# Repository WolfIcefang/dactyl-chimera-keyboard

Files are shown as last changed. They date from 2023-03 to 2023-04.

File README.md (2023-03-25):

# dactyl-chimera-keyboard

## A mechanical keyboard designed for 3D printing, tinkering, and experimentation.





This project aims to provide a "test bench" for various column curvatures in mechanical keyboards. Potential side effects include: shorter 3d printing times, instant fine-tuning of column height and stagger, [adjustable tenting](https://youtu.be/rMioYSjqEoU), and comfortable computer usage. Interchangable thumb clusters are also a goal of the project, but currently there's only one thumb cluster to choose from.

Dactyl Chimera (DC)'s primary purpose is as a testing and research tool. It is not designed to look stylish, sound spectacular, or increase compactness. If you do not mind a couple (dozen) dangling wires or visible screws, DC should offer adequate reliablility and durability for long-term, even permanent, use.

## How it works (and why it's awesome):

### Dactyl Chimera is comprised of three main components: the arches, the rack, and the tenting foot.

**The Rack** is similar to the bottom plate of a traditional keyboard. It is mostly flat and has a pattern of screw holes to mount the other components.

**The Tenting Foot** mounts to the underside of the rack. Because the foot is entirely responsible for the tenting angle, a DC Rack without any tenting is completely flat and can be modeled parallel to the XY origin plane. The current tenting foot is a simple kickstand. It cannot be typed on when folded flat; it was just easier to model and print this way. It provides a tenting angle of 40 degrees. You can design any type of tenting foot you desire to give Dactyl Chimera your perfect tenting angle.

**The Arches** are the keyboard's switch columns and front/back walls. Each arch contains one column of switches, except for the outer (pinky) arch which contains two columns. Arches mount directly to the rack, not to one another. Because each column can be printed independently, failed prints don't waste your whole day and successful prints don't use a ton of support material. Because arches mount directly to the rack, and the rack is parallel to the CAD software's base plane, there is no need to factor in the keyboard's tenting angle while designing a column. Finally, because arches are not connected to each other, changes in height from one column to the next never cause keycap interference.

## How to participate:

Dactyl Chimera is designed in FreeCAD and will be recreated in SolveSpace once the design is proven to work well. If you prefer a different 3D modeling platform, use the \[sizing chart\] (coming soon) to help fit your arches to the rack. If you don't know anything about 3D modeling, you can download a set of "standard" STL files from releases page, however, if you own a 3D printer, I HIGHLY recommend learning FreeCAD.

You should also join the Dactyl Chimera Center in [Matrix](https://matrix.to/#/!mArixoOlqsCQNWsaFc:matrix.org?via=matrix.org). The Dactyl Chimera Center is a great(?) place to troubleshoot problems, discuss improvements, and share successful builds. You can also use the Issues and Pull request tools in this GitHub repo.

Wiring up a Dactyl Chimera should be similar to wiring up a Squeezebox. Solder wires to the switch pins to make the pins longer before sticking the switches into the keyboard, then solder those wires to each other. I haven't wired mine yet or worked on the software, so this might be terrible advice. Dactyl Chimera is a case first and a keyboard second. (in other words it's not a fully functional keyboard yet.)

## Designing a keymap

Dactyl Chimera is a 5 row, 6 column layout. Having anything bigger than a 40% may be intimidating to some of you, but this section will teach you that it's actually okay to use large keyboards. First, why so many keys? Simply put, Dactyl Chimera needs to be massive so that it can accommodate both large and small layout experiments. Equally importantly, bigger curves provide more space to hide screws.

### But what do I do with all these keys?

First off, you don't need to use all the keys on this keyboard. You can go as small as the asetniop layout; you don't even need to put switches into all the holes. That said, even if you stick with a smaller layout, you may want to fill the top and bottom rows with macros. These "extra keys" can be used to quickly accommodate a strange keyboard shortcut, (for example, "why does Microsoft Excel force me to use F2 as the Edit Cell shortcut?"), to temporarily patch a deficit in your layout, ("I didn't realize I needed an Enter key on my left hand!"), or for actions you often take when your hands aren't settled into a typing rhythm. ("Leave Zoom Meeting" and "mute computer" are among my top picks.)

### But I use a full size keyboard! Where are my arrow keys and function row?

Dactyl Chimera has almost as many keys as a 60% keyboard, depending on your thumb cluster choice. Included with each release is a spreadsheet showcasing the best layouts available. The Traditional-ish layout should appease fans of bigger keyboards. If it doesn't appease you, suggestions are always welcome. 

### Understanding the basic theories of keyboard layout design:

For beginners, I'd recommend reading Thomas Baart's Guide to working with a small keyboard https://blog.splitkb.com/how-to-work-with-small-keyboards

Once you're beyond the basics, you might want to check out:

DreymaR's explanation of "[Extend](https://dreymar.colemak.org/layers-extend.html)", for where to put your arrow keys.

[Precondition's Guide to Home Row Mods](https://precondition.github.io/home-row-mods) **VS** [why you shuold BAN Key Chords](http://xahlee.info/kbd/banish_key_chords.html) for where to put shift, ctrl, and more.

I use Colemak mod-DH and highly recommend it. It helps my fingers rest on the keyboard instead of hovering above it. It's easy to learn using the [Tarmak](https://dreymar.colemak.org/tarmak.html) system!

I challenge someone to combine [Asetniop](http://asetniop.com/) with 50 macro keys. There is no reward.

Finally, start thinking about your layout now! You'll want the software to be ready when the keyboard is done printing. 

### Okay but we need firmware!

Yeah, well, I need firmware too. I have not wired up my own keyboard yet, and will definitely need help getting QMK working. I intend to use my keyboard with Vial (a real-time QMK keymap editor), and I believe "official" ZMK firmware support would also be good.

## History of the Dactyl / Special Thanks:

The original [Dactyl keyboard](https://github.com/adereth/dactyl-keyboard), created by Adareth, is a 3D printable adaptation of the Kinesis Advantage keyboard. The Kinesis Advantage, in turn, bears a striking resemblance to the even older Maltron Keyboard. Dactyl Chimera also takes inspiration from the bezel-free sides of the [Dactyl Manuform](https://github.com/tshort/dactyl-keyboard), the adjustability of the [Squeezebox keyboard](https://peterlyons.com/problog/2021/04/squeezebox-keyboard/), the Tenting Puck of the [Kyria](https://splitkb.com/products/tenting-puck) and the many discussions in the #kb-ergo channel at the [MechKeys Discord](https://discord.gg/mechkeys).

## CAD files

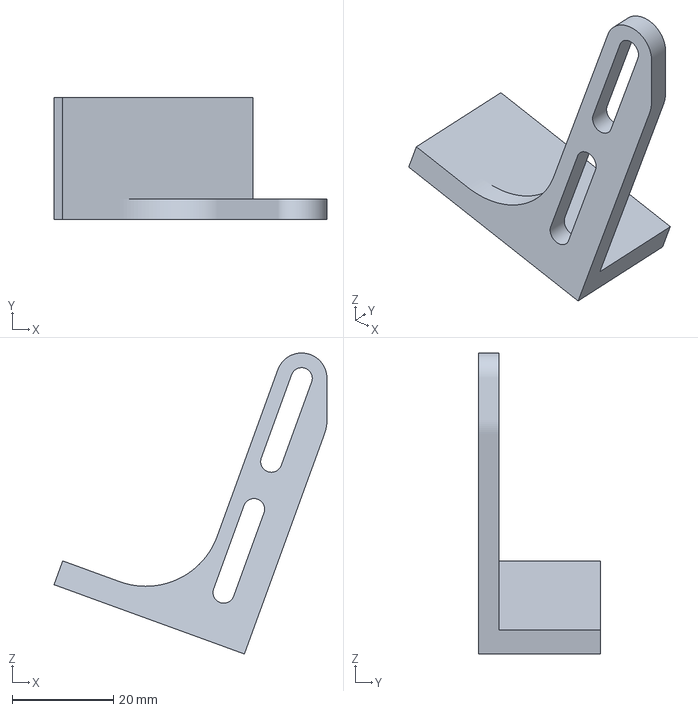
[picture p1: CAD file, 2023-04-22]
3mf files/Dactyl Chimera V3-Tenting PartTentingFoot.3mf
53.9 x 24.0 x 59.4 mm

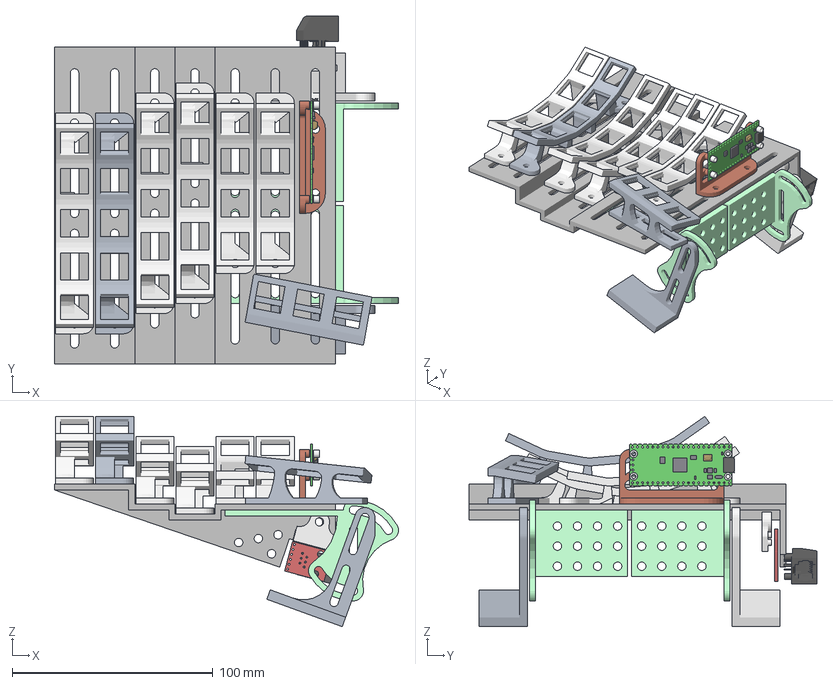
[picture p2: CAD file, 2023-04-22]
Dactyl Chimera V3.FCStd
171.4 x 173.3 x 104.8 mm
OuterArch
PinkieArch
RingArch
MiddleArch
IndexArch
InnerIndexArch
BasePlate
Thumb Cluster
PicoStandoffs x 4
PICO_REF_BOARD.STEP
PICO_REF_USB.STEP
PICO_REF_SWITCH.STEP
PICO_REF_MICROCONTROLLER.STEP
PICO_REF_LED.STEP
PICO_REF_ONSEMI.STEP
PICO_BOURNS.STEP
PICO_MURATA.STEP
PICO_MURATA.STEP001
PICO_RICHTEK.STEP
PICO_DIODES.STEP
PICO_AEL.STEP
PICO_WINBOND.STEP
PicoBase
RJ11-6
RJ11Holder
TentingFoot
TentingLeg
TentingLeg (Mirror #1)
TentingFoot (Mirror #2)
RJ11 Breakout

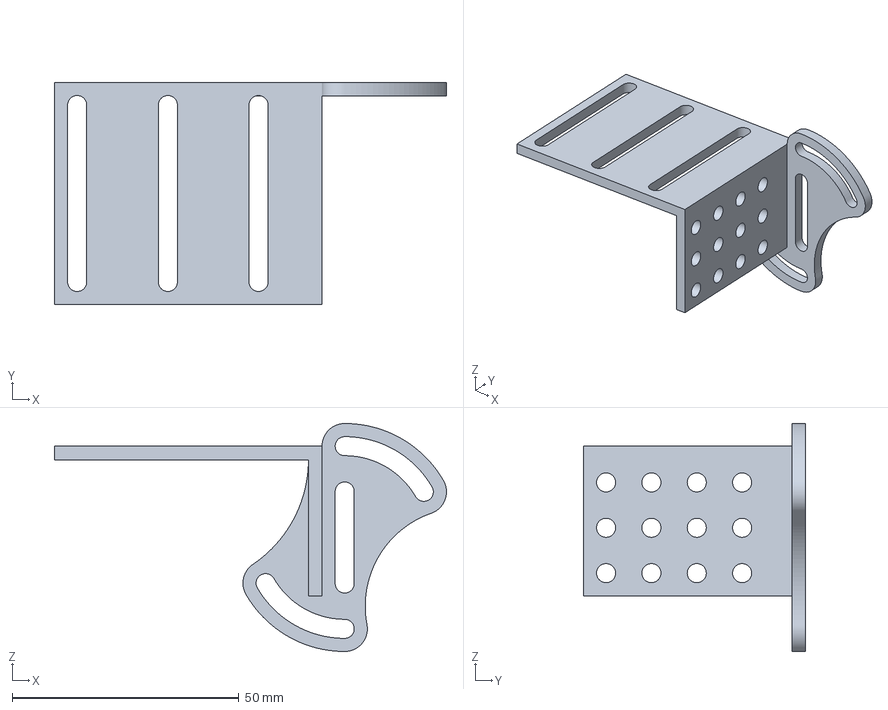
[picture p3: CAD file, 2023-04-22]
3mf files/Dactyl Chimera V3-Tenting PartTentingLeg.3mf
86.4 x 49.0 x 50.3 mm

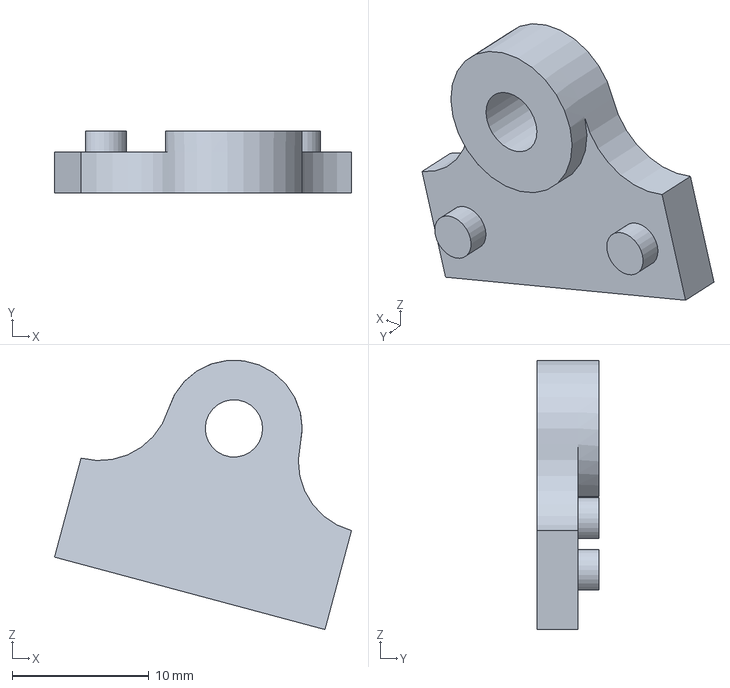
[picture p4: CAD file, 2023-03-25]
3mf files/Dactyl Chimera V3-RJ11Holder.3mf
21.7 x 4.57 x 19.7 mm

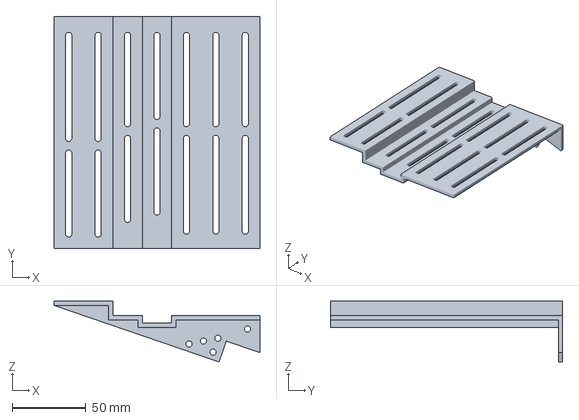
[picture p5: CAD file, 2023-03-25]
3mf files/Dactyl Chimera V3-BasePlate.3mf
140.0 x 158.0 x 41.4 mm

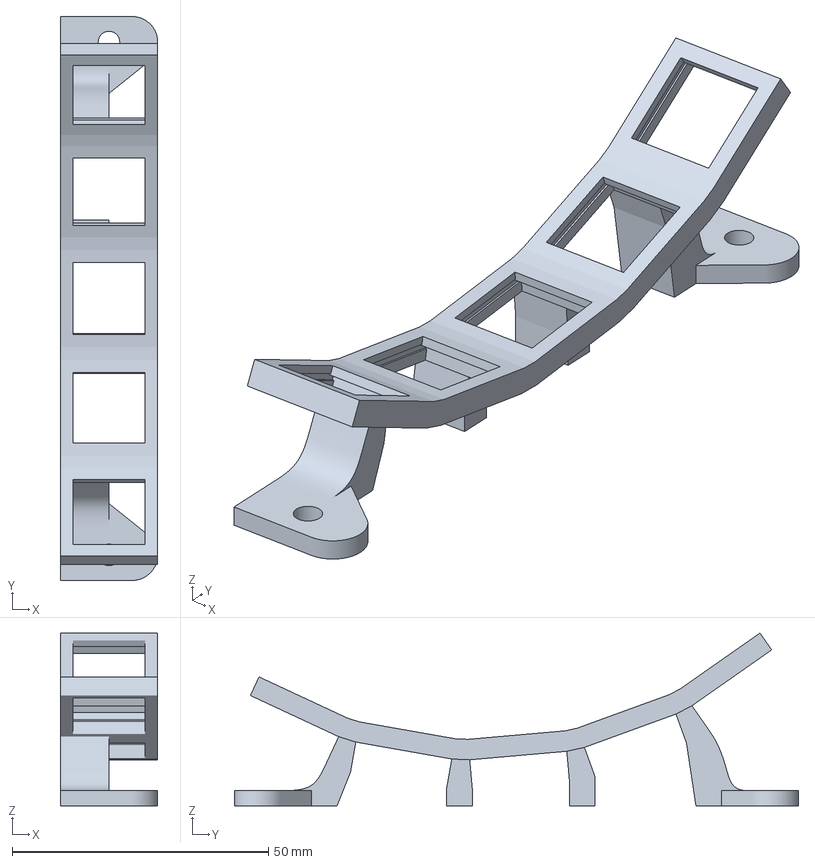
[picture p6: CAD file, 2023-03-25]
3mf files/Dactyl Chimera V3-OuterArch.3mf
19.0 x 110.0 x 33.7 mm

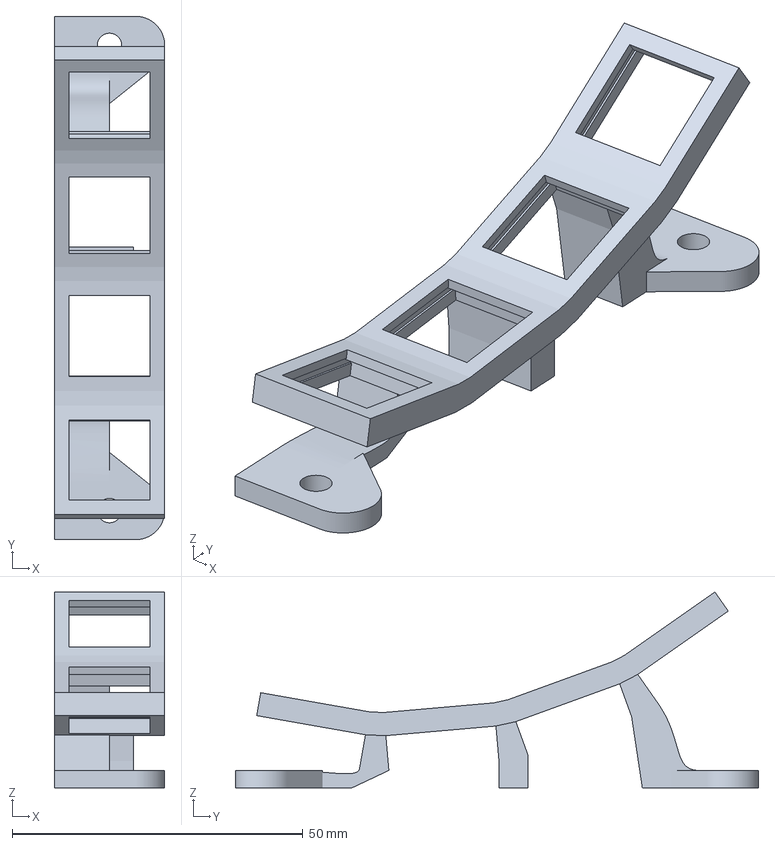
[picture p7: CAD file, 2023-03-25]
3mf files/Dactyl Chimera V3-IndexArch.3mf
19.0 x 90.0 x 33.7 mm

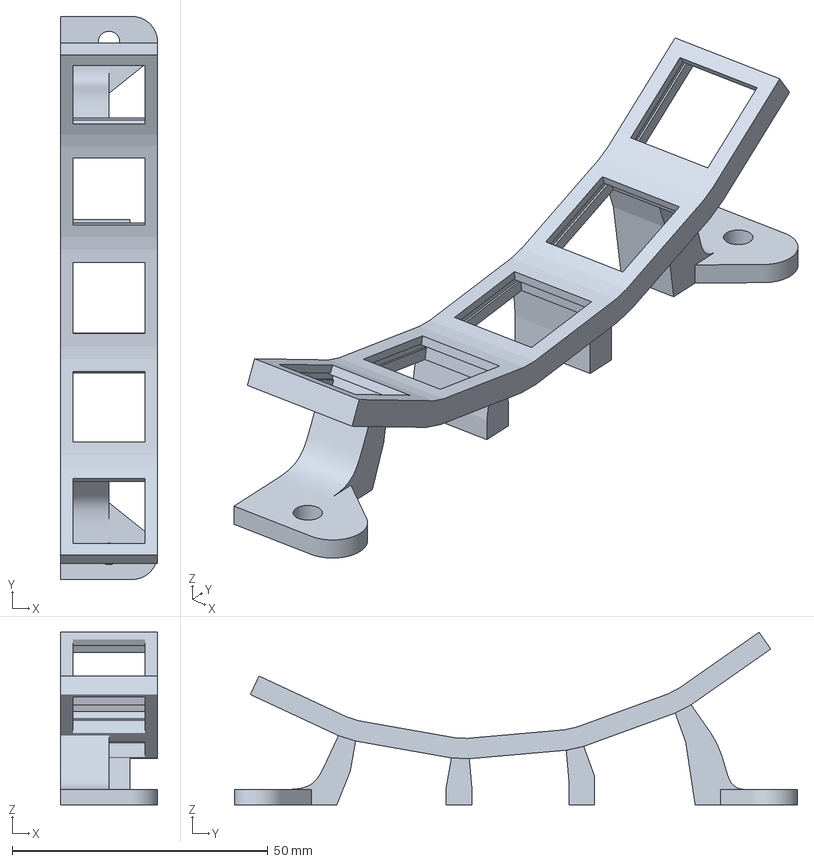
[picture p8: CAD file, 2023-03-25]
3mf files/Dactyl Chimera V3-MiddleArch.3mf
19.0 x 110.0 x 33.7 mm

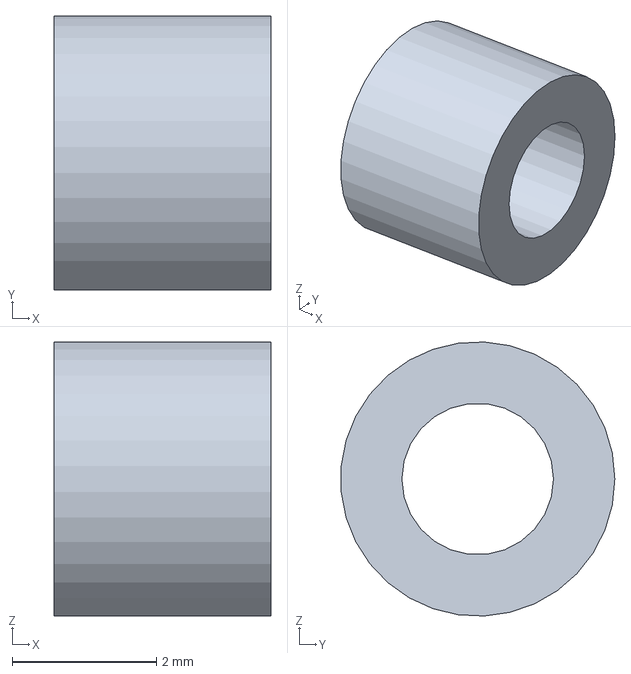
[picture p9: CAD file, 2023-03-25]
3mf files/Dactyl Chimera V3-PicoStandoffs.3mf
3.00 x 3.79 x 3.80 mm

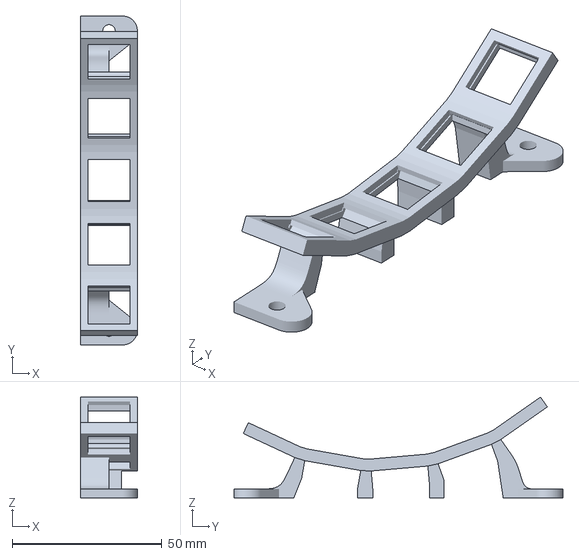
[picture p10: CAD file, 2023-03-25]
3mf files/Dactyl Chimera V3-PinkieArch.3mf
19.0 x 110.0 x 33.7 mm

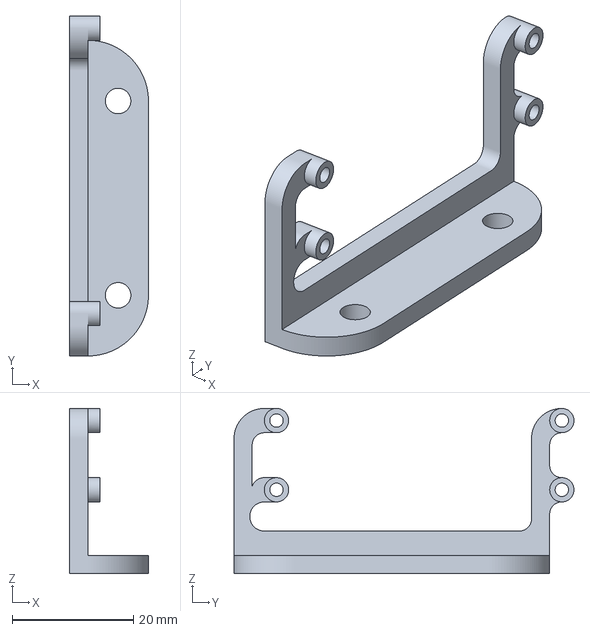
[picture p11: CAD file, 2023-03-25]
3mf files/Dactyl Chimera V3-PicoBase.3mf
13.0 x 56.0 x 27.2 mm

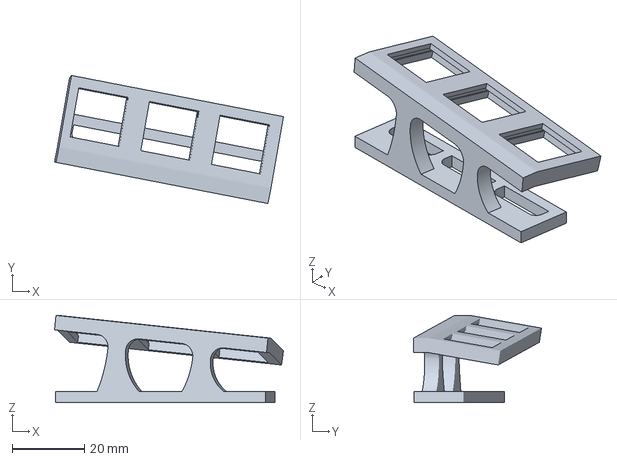
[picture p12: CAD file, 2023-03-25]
3mf files/Dactyl Chimera V3-Thumb Cluster.3mf
63.3 x 35.4 x 24.1 mm

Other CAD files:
3mf files/Dactyl Chimera V3-RingArch.3mf
3mf files/Dactyl Chimera V3-InnerIndexArch.3mf

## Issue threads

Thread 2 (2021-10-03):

We should have a proper build guide

WolfIcefang, 2021-10-03:
It makes the most sense for the Build Guide to be a folder in this repository. That way it included in offline downloads, changes are supervised, and updates are timestamped to match changes in the model. However, what should be in a build guide?

- Designing a layout - I like to work on the layout while building the physical keyboard, that way I'm ready to get typing by the time I get to the "Software" stage.
- Buying components.
- Hand sizing chart, and using 3D modeling software
- how to 3d print the pieces
- soldering and wiring
- Software and firmware

A few other thoughts:
Links to external resources should be used whenever possible. For example, it would be better to link to Reddit's part buying guides instead of creating our own part buying guide. This makes it easier to keep information up-to-date for everyone, not just ourselves. Obviously some information, like "what brand of screws work best" can written from scratch.
When multiple choices for products exist, for example 3D printing filament or keyboard firmware, as many options should be compiled as is possible and ranked. Listing many options helps the guide remain relevant, and ranking the options makes it easier to read the build guide quickly.

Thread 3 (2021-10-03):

The rack is too big!

WolfIcefang, 2021-10-03:
For Dactyl Chimera V1:
The rack takes 6 to 9 hours to print and it barely fits on a Dremel build plate. Each piece of Dactyl Chimera should be printable within an afternoon.
Potential fixes:
The rack could be split into 3 bodies: the front row underside, the back row underside, and the vertical stagger lock. The "slots" half could be printed on the arches, while the "holes" are part of the rack.
A fourth part of the rack could help keep the front and back row underside parts parallel.

dakipro, 2021-12-23:
could it be done in some sort of open frame, similar to this?
https://www.reddit.com/r/ErgoMechKeyboards/comments/p0pm1l/dactyl_flex/
or something like a "peg board frame" instead of the solid (I just started with 3d printing world, have zero experience to actually help with the model, yet)

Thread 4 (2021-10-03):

FreeCAD sketches can break if values are changed too much

WolfIcefang, 2021-10-03:
I am well aware of the fact that certain sketches may rearrange themselves if a dimension is changed by a large amount. (for example causing other dimensions to change from a positive to negative). A lot of  trial and error will be necessary to make inputting hand sizes a seamless experience.
While these kinks get worked out, this has helped me resize parts of my model:
while in sketcher workbench:
turn off "auto remove constraints"
turn on "auto update"
Change the dimension in small increments, such as 5mm or even 1mm at a time, and wait for the model to regenerate. Jumping by 50mm IS going to have side effects, at least until the model is improved.
And remember to save your work often!

If your model breaks as a result of resizing, feel free to document it in this issue thread.

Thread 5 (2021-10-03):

The default Tenting Foot should be height-adjustable, not folding.

WolfIcefang, 2021-10-03:
Currently, the Tenting Foot provided in the official Dactyl Chimera release folds up for portability, but only tents the keyboard by a set amount. Since the Dactyl Chimera is designed for people who aren't sure what shape they want their keyboard to be, it makes more sense for the official tenting foot to be adjustable. This will save time and plastic.
Of course, designs for an adjustable tenting foot still need to be drawn up, and I am preoccupied with the rack redesign.

dakipro, 2021-12-23:
could this be solved with an adjustable bolt, something like this? https://www.reddit.com/r/MechanicalKeyboards/comments/g3aue6/the_dactylmanuformrtrack_with_qmk_features_on_a/
just have holes for bolts on strategic places

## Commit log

2021-10-14 Updates to tenting foot and thumb cluster
    This update removes most, if not all, uses of the "up to face" padding tool from the Tenting Foot. It turns out "up to face" is still pretty buggy in FreeCAD. You can still adjust the tenting angle of the keyboard, but you cannot change the location of Tenting foot's planes. In the future, the plane locations will be set by the spreadsheet and this will not be an issue. On the plus side, Tenting foot A and Tenting foot B are now identical, so if you accidentally print the same one twice it will still work.
    The thumb cluster now has a horizontal screw slot instead of 2 screw holes. You should now be able to slide the cluster left and right as well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
    [Dactyl Chimera.FCStd]
2021-10-14 Delete Dactyl Chimera-Arch 4.stl
    I can't upload the .stl files directly to main, because they don't go into the proper folder. This was just a test. Sorry if this sent an email to anyone.
    [Dactyl Chimera-Arch 4.stl]
2022-02-25 Minor update to personal layout
    This is just some minor improvements to my personal Chimera layout. I'm not satisfied with it yet; I think I'll need a dedicated mouse input layer.
    If you're getting notifications on this repo, I do have big plans for a V2.0 and QMK, but it might be a few months before I can commit real time to this project again. It depends on my school workloa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
    [Dactyl Chimera Layouts.ods]
2022-02-26 Improvements to my layout template
    I added a really nice gaming layer and a mouse layer because I hurt my index finger from excessive clicking.
    It's still not done, I think I need to rearrange my layers so I don't get trapped on one of them.
    For info on the how and why of the layout, I'll be writing it into the spreadsheet itself eventually.
    Spreadsheet-based layouts makes it easier to use Vial-QMK.
    [Dactyl Chimera Layouts.ods]
2022-04-30 Update Dactyl Chimera FreeCAD body list .txt
    Changed tenting screw back to tenting foot
2022-05-12 Added the Dactyl Chimera V3 file
    This is the outer column of Dactyl Chimera V3. I'll be printing it today to see how it holds up.
    [Dactyl Chimera V3.FCStd]
2022-11-28 Updated Dactyl v3 FreeCAD files
    [Dactyl Chimera V3.FCStd]
2022-12-24 Near complete rendition of V3
    The drawings of parts is "done". I'll just need to adjust variables to make it look pretty.
    [Dactyl Chimera V3.FCStd]
2023-02-01 Just an update because it has been a month
    [Dactyl Chimera V3.FCStd]
2023-02-15 Dactyl Chimera V3 latest version
    The two copies are slightly different because my Nextcloud sync isn't working right now. I will delete the duplicate file once I've got it fixed.
    [Dactyl Chimera V3 copy.FCStd]
2023-03-25 Delete Dactyl Chimera stl files directory
    Replacing with 3mf files
    [Dactyl Chimera-Arch 01.stl, Dactyl Chimera-Arch 2.stl, Dactyl Chimera-Arch 3.stl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]
2023-03-25 Delete Dactyl Chimera V3 copy.FCStd
    No need for this copy any more
    [Dactyl Chimera V3 copy.FCStd]
2023-03-25 Delete Dactyl Chimera.FCStd
    This is the old version
    [Dactyl Chimera.FCStd]
2023-03-25 Add files via upload
    Release version of Dactyl Chimera V3
    [Dactyl Chimera V3.FCStd]
2023-03-25 Add files via upload
    Quick fix to Dactyl Chimera release version
    [Dactyl Chimera V3.FCStd]
2023-03-25 added 3mf files of complete dactyl chimera
    [Dactyl Chimera V3-BasePlate.3mf, Dactyl Chimera V3-IndexArch.3mf, Dactyl Chimera V3-InnerIndexArch.3mf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]
2023-04-22 Universal Tenting Leg update
    This update adds a new Tenting Leg and Tenting foot design. You will no longer have to print a new tenting leg every time you change the base plate.
    [Dactyl Chimera V3-Tenting PartTentingFoot.3mf, Dactyl Chimera V3-Tenting PartTentingLeg.3mf, Dactyl Chimera V3.FCStd]
